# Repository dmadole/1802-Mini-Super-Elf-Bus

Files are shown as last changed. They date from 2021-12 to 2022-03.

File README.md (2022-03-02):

# 1802-Mini-Super-Elf-Bus-Adapter
This is a bus adapter card for the Quest Super Elf that adapts it to expansion cards for the [1802/Mini](https://github.com/dmadole/1802-Mini) system. It supports the following features:

* Connects to 50-pin expansion connector on Super Elf
* 64K of memory in two 32K RAM, EPROM, or EEPROM devices
* Supports 62C64, 62C256, 27C64, 27C256, 28C64, 28C256
* Can temporarily map a ROM at $8000 to $0000 with M key
* TTL level port with Q and selectable EF pin for soft serial
* Transmit and receive polarity selectable on serial port
* Buffered data bus for reliability across ribbon cable
* Additional pull-up resistors for improved rise time on inputs
* Voltage regulator allows powing expansion cards from Super Elf
* Mini-USB connector for independent 5 volt power input
* Form factor allows stacking or backplane by connector choice
* Highly annoted silkscreen documents most settings and pins

Gerber files for the PCBs and PDF schematics can be found in [Releases](https://github.com/dmadole/1802-Mini-Super-Elf-Bus/releases).

BOMS and any applicable errata or other notes can be found in [notes](https://github.com/dmadole/1802-Mini-Super-Elf-Bus/tree/main/notes).

For availability of kits and bare PCBs please see http://madole.net/1802/mini/kits

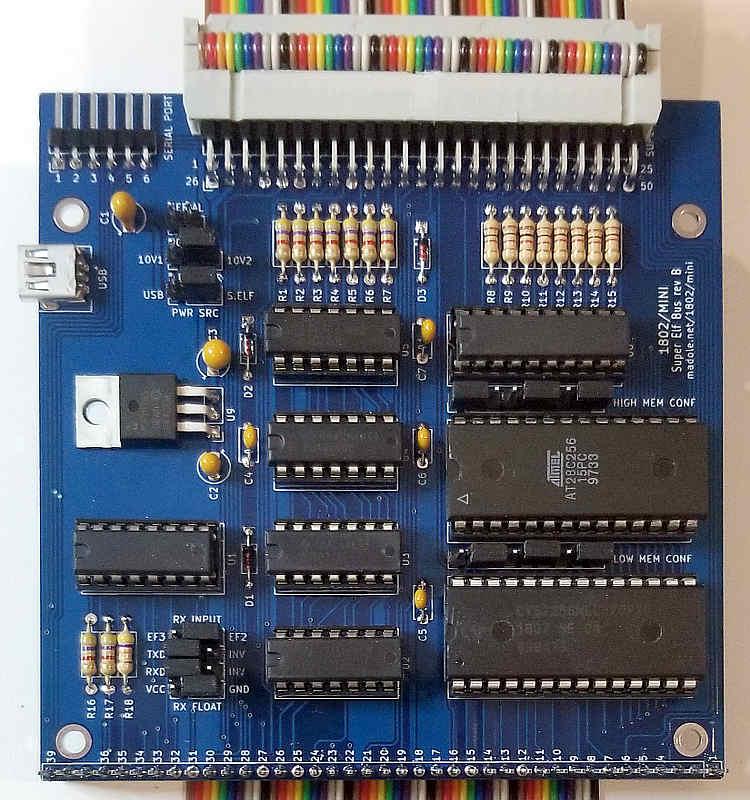
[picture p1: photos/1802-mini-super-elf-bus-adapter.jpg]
1802/Mini Super Elf Bus Adapter

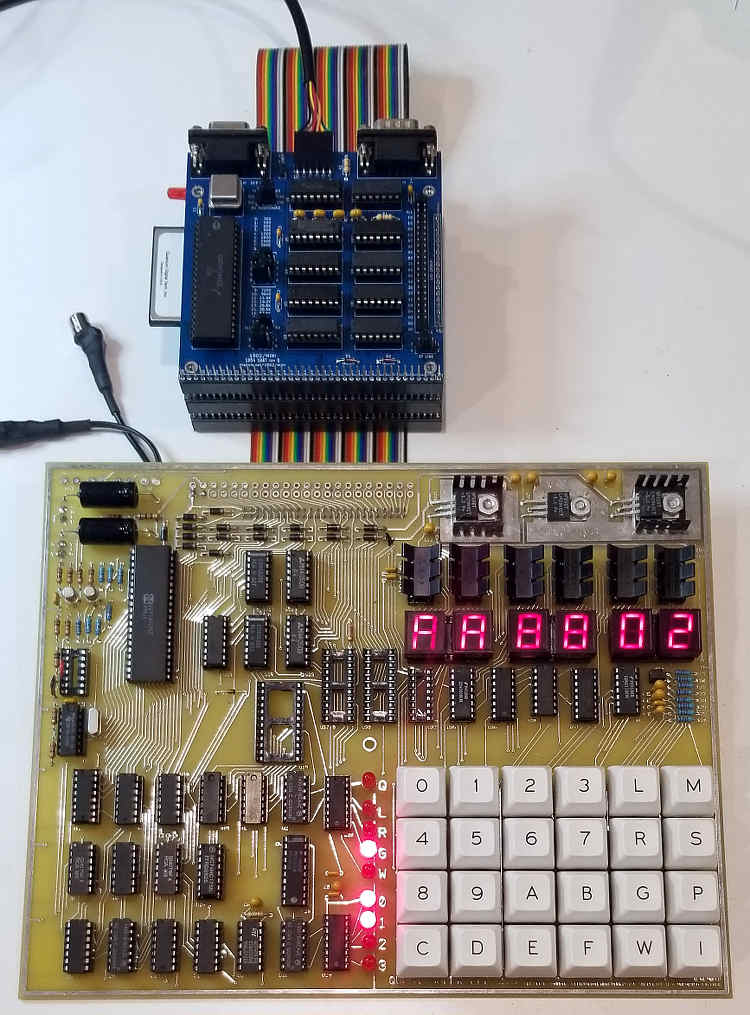
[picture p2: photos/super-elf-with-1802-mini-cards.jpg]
Super Elf with 1802/Mini Cards


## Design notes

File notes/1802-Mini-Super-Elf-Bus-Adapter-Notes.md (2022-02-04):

# 1802/Mini Super Elf Bus Adapter Notes

Please see any [applicable errata](https://github.com/dmadole/1802-Mini-Processor/tree/main/notes) before assembling.

## Super Elf Bus Connector

When soldering the 50-pin connector for the ribbon cable that goes to the Super Elf, if you are using an unshrouded connector, be sure to leave enough clearance from the board to be able to plug your connector in. By itself, a "standard" unshrouded connector sits too low to the board for a typical ribbon cable IDC connector to fit. The easy way to deal with this is to plug your cable into the connector before soldering the connector to the board.

The 50-pin connector should be installed on the "top" component side of the adapter board, and the 50-pin connector on the Super Elf should be installed on the "bottom" solder side of the Super Elf. If for some reason the 50-pin connector is already installed on the "top" component side of your Super Elf, you will need to install the connector on the adapter on the "bottom" solder side instead to compensate (or make a special ribbon cable with the even and odd pins reversed on one end).

## CLEAR Signal on Bus Connector

The bus adapter and most 1802/Mini peripheral cards need the 1802 CLEAR- signal, however this was not provided on the 50-pin expansion connector in the Super Elf design. Since the original on-board RAM is no longer needed with the bus adapter, the CS pin on the Super Elf expansion has been re-purposed to carry the CLEAR- signal, which requires slight modification to the Super Elf:

1. Remove the two 256-byte RAM chips
2. Solder a jumper from CLEAR- to CS

A convenient place to put the jumper is between U19 (1861) pin 8 (CLEAR-) and U27 (2101) pin 17 (CS) since these are adjacent chips and the jumper is short. The 22K pull-up resistor on the board for CS can be left in place.

Alternatively, if you don't want to modify the Super-Elf, you could lift the wire from the  CS pin in the ribbon cable and connect it somewhere on the board where CLEAR- is present, perhaps with a mini-hook clip. If you arrange to ground the CS pin on the ribbon connector where the wire would have been, it will not be necessary to remove the RAMs from the Super Elf. 

## Power Input Source

You can power the bus adapter from the Super Elf by using the on-board regulator by jumpering "PWR SRC" to "S.ELF" and selecting which of the two power busses from the Super Elf you want to use with the "S.ELF PWR" jumper. Otherwise, the bus adapter and expansion cards can be powered separately using the mini-USB connector by jumpering "PWR SRC" to "USB". Or it can be arranged to input power on the 1802/Mini bus VCC and GND pins.

## Memory Mapping

The low memory socket is mapped at 0000 and the high at 8000. Pressing the "M" key causes the high socket to appear at both 0000 and 8000 after system reset until the first read of an address at 8000 or above. This can be used to bootstrap a system from ROM that normally has RAM at 0000 by putting a jump instruction to high address space in the start of the ROM. Many existing ROM images work with this either intentionally or unintentionally as they start with a long jump instruction.

The "G" key will start execution with the RAM mapped at 0000 and so can be used to execute code in RAM that was input from the keypad.

## Serial Port Polarity

The normal RX and TX jumper settings for use with typical 5 volt level serial interfaces and most software is TX and RX non-inverted, and RX at VCC. These can need to be reversed, however, depending on how software is written. Use EF3 for RX for running membership card software or EF2 for running Pico/Elf software.

## Serial Port Speed

The timing parameters of the standard software UART in the Elf/OS BIOS are not well suited to the Super Elf clock rate, so the highest serial speed that can be expected at 1.79 MHZ is 1200 baud, or at 3.58 MHz is 2400 baud. The nitro software UART can be loaded though to use up to 9600 baud at 1.79 Mhz or 19200 baud at 3.58 Mhz. Be sure to use the "-k" option to nitro to specify the clock rate if also specifying a baud rate, for example, "nitro -k 1790 9600"

## Jumper Settings

The following are the recommended jumper settings for use with Elf/OS. These assume 32K RAM in low memory from 0000-7FFF and 32K EEPROM in high memory from 8000-FFFF, use of EF2 for serial input, and startup from ROM. These give compatibility with software intended for the Pico/Elf and so is most convenient for use with software for Elf/OS.

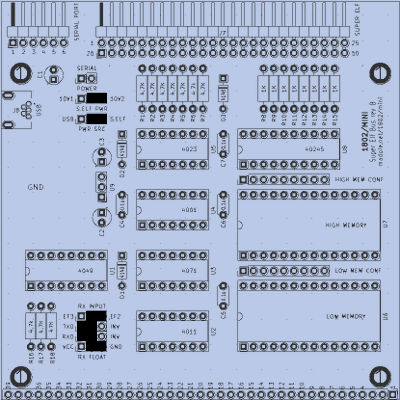
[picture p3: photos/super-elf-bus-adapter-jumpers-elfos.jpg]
Super Elf Bus Adapter Jumpers


If you are using an 1802/Mini specific build of Elf/OS BIOS that supports the 1854 UART with auto-detection of which port to use, you will want to set the RX GND jumper instead of RX VCC. This allows the BIOS to detect on EF2 when no cable is connected. Note that this does prevent EF2 from being used for anything else. This firmware is here:

https://github.com/dmadole/1802-Mini/tree/master/firmware

There is a specific build for the Super Elf, which has the clock rate defined as 1790 KHz and the baud rate fixed at 1200 baud.

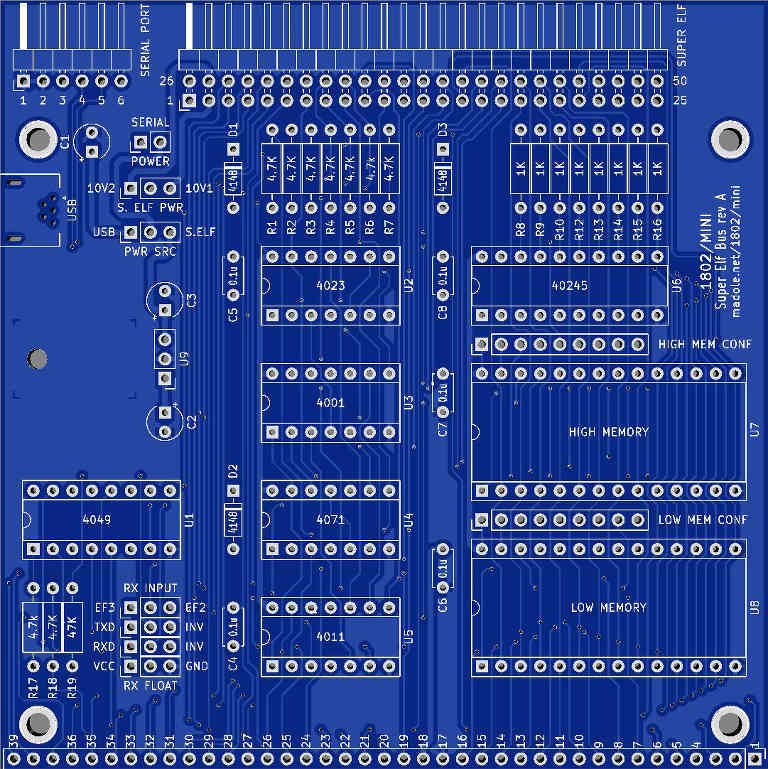
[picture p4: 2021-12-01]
photos/1802-Mini-Super-Elf-Bus-Rev-A-Rendering.jpg

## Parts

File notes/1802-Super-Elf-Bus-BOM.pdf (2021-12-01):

SUPER ELF BUS ADAPTER

Qty | Description | Manufacturer Manufacturer # | Vendor | Vendor # | Price | Qty | Total

Integrated Circuits
1 | 32K x 8 CMOS SRAM | Sharp | LM62256L-70 | Jameco | 82472 | 3.95 | 1.00 | 3.95
1 | 32K x 8 CMOS EEPROM | Atmel | 28C256-25 | Jameco | 74878 | 4.95 | 1.00 | 4.95
1 | CD4001 | TI | CD4001BE | Digikey | 296-2028-ND | 0.68 | 1.00 | 0.68
1 | CD4011 | TI | CD4011BE | Digikey | 296-2031-ND | 0.68 | 1.00 | 0.68
1 | CD4023 | TI | CD4023BE | Digikey | 296-2041-ND | 0.68 | 1.00 | 0.68
1 | CD4071 | TI | CD4071BE | Digikey | 296-2062-ND | 0.68 | 1.00 | 0.68
1 | CD4049 | TI | CD4049UBE | Digikey | 296-2055-5-ND | 0.68 | 1.00 | 0.68
1 | CD40245 (or 74C245 or 74HC245) | TI | SN74HC245N | Digikey | 296-1584-5-ND | 0.68 | 1.00 | 0.68
1 | LM2940CT | TI | LM2940CT-5.0/NOPB | Digikey | LM2940CT-5.0/NOPB-ND | 1.96 | 1.00 | 1.96

Discrete Components
8 | Resistor 1/4 watt 1K | Stackpole | CF14JT1K00 | Digikey | CF14JT1K00CT | 0.10 | 8.00 | 0.80
9 | Resistor 1/4 watt 4.7K | Stackpole | CF14JT4K70 | Digikey | CF14JT4K70CT-ND | 0.10 | 9.00 | 0.90
1 | Resistor 1/4 watt 47K | Stackpole | CF14JT47K0 | Digikey | CF14JT47K0CT-ND | 0.10 | 1.00 | 0.10
3 | Diode 1N4148 | ON Semi | 1N4148 | Digikey | 1N4148FS-ND | 0.10 | 3.00 | 0.30
5 | Ceramic capacitor 0.1uF radial 0.2" | AVX | SR215C104KAA | Digikey | 478-2472-ND | 0.51 | 5.00 | 2.55
1 | Tantalum capacitor 0.47uF radial 0.1" | AVX | TAP474K035SCS | Digikey | 478-1900-ND | 0.68 | 1.00 | 0.68
1 | Tantalum capacitor 10uF radial 0.1" | AVX | TAP106K010SCS | Digikey | 478-1838-ND | 0.80 | 1.00 | 0.80
1 | Tantalum capacitor 22uF radial 0.1" | AVX | TAP226K010SCS | Digikey | 478-1874-ND | 1.13 | 1.00 | 1.13

Interconnects
1 | Straight header 2 pins 0.1" | Sullins | PREC002SAAN-RC | Digikey | S1012EC-02-ND | 0.06 | 1.00 | 0.06
6 | Straight header 3 pins 0.1" | Sullins | PREC003SAAN-RC | Digikey | S1012EC-03-ND | 0.09 | 6.00 | 0.54
2 | Straight header 9 pins 0.1" | Sullins | PREC009SAAN-RC | Digikey | S1012EC-09-ND | 0.21 | 2.00 | 0.42
1 | Right-angle header 6 pins 0.1" | Sullins | PREC006SBAN-M71RC | Digikey | S1112EC-06-ND | 0.19 | 1.00 | 0.19
1 | Right-angle header 50 pins 0.1" | Sullins | PREC025DBAN-M71RC | Digikey | S2112EC-25-ND | 1.41 | 1.00 | 1.41
13 | Jumper shunts 0.1" | Sullins | STC02SYAN | Digikey | S9000-ND | 0.10 13.00 | 1.30
1 | Socket 39 pin 0.1" long tail for stacking | Samtec | SSQ-139-03-T-S | Digikey | SAM1206-39-ND | 4.52 | 1.00 | 4.52
1 | Mini-USB receptable AB | Molex | 565790519 | Digikey | WM17121-ND | 2.54 | 1.00 | 2.54

Sockets
2 | DIP socket 28 pin 0.6" | On Shore | ED28DT | Digikey | ED3052-5-ND | 0.34 | 2.00 | 0.68
1 | DIP socket 20 pin 0.3" | On Shore | ED20DT | Digikey | ED3054-5-ND | 0.26 | 1.00 | 0.26
1 | DIP socket 16 pin 0.3" | On Shore | ED16DT | Digikey | ED3046-5-ND | 0.19 | 1.00 | 0.19
4 | DIP socket 14 pin 0.3" | On Shore | ED14DT | Digikey | ED3045-5-ND | 0.19 | 4.00 | 0.76

Mechanical
4 | 0.5 inch standoff spacer | RAF | 4505-440-AL-7 | Jameco | 393474 | 0.49 | 4.00 | 1.96
1 | Circuit Board | Madole | | JLCPCB | | 3.00 | 1.00 | 3.00
| | | | | | Total | | 40.03

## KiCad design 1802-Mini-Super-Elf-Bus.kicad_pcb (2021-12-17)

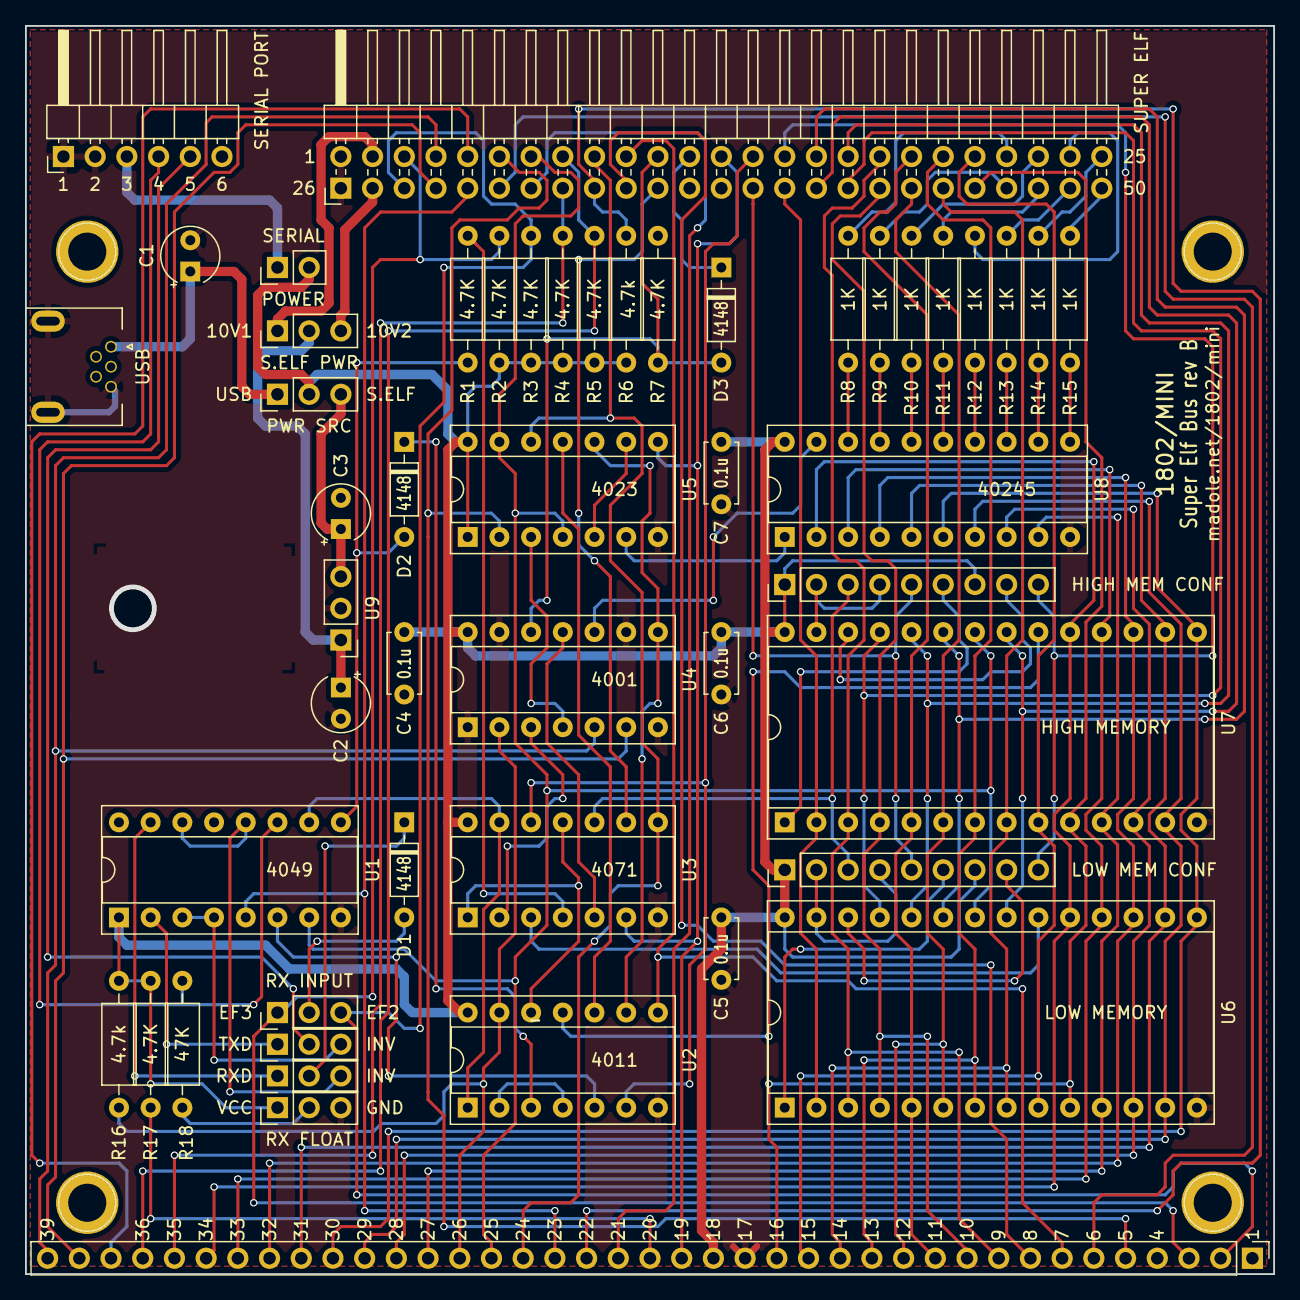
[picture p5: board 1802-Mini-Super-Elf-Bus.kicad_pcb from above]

Board: 2 copper layers, 100.0 x 100.0 mm, 54 parts (0 on the bottom side), 103 nets.

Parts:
C1: 10uF; CP_Radial_Tantal_D4.5mm_P2.50mm
C2: 0.47uF; CP_Radial_Tantal_D4.5mm_P2.50mm
C3: 22uF; CP_Radial_Tantal_D4.5mm_P2.50mm
C4, C5, C6, C7: 0.1u; C_Disc_D4.7mm_W2.5mm_P5.00mm
D1, D2, D3: 4148; D_DO-35_SOD27_P7.62mm_Horizontal
J1, J2, J3, J4: Mount; 1pin
J5: 1802/Mini Bus; PinHeader_1x39_P2.54mm_Vertical
J6: SLOT_1_CONFIG; PinHeader_1x09_P2.54mm_Vertical
J7: Super Elf Bus; PinHeader_2x25_P2.54mm_Horizontal_Row1_Row2
J8: USB PWR; USB_Mini-AB_Molex_56579_0519
J9: Serial Port; PinHeader_1x06_P2.54mm_Horizontal
J10: SLOT_2_CONFIG; PinHeader_1x09_P2.54mm_Vertical
JP1: POWER; PinHeader_1x02_P2.54mm_Vertical
JP2, JP3: PWR SRC; PinHeader_1x03_P2.54mm_Vertical
JP8: TX_INV; PinHeader_1x03_P2.54mm_Vertical
JP9: RX_SEL; PinHeader_1x03_P2.54mm_Vertical
JP10: RX_INV; PinHeader_1x03_P2.54mm_Vertical
JP11: RX_IDL; PinHeader_1x03_P2.54mm_Vertical
R1, R2, R3, R4, R5, R6, R17: 4.7K; R_Axial_DIN0207_L6.3mm_D2.5mm_P10.16mm_Horizontal
R7, R16: 4.7k; R_Axial_DIN0207_L6.3mm_D2.5mm_P10.16mm_Horizontal
R8, R9, R10, R11, R12, R13, R14, R15: 1K; R_Axial_DIN0207_L6.3mm_D2.5mm_P10.16mm_Horizontal
R18: 47K; R_Axial_DIN0207_L6.3mm_D2.5mm_P10.16mm_Horizontal
U1: 4049; DIP-16_W7.62mm_Socket
U2: 4011; DIP-14_W7.62mm_Socket
U3: 4071; DIP-14_W7.62mm_Socket
U4: 4001; DIP-14_W7.62mm_Socket
U5: 4023; DIP-14_W7.62mm_Socket
U6: LO_MEM; DIP-28_W15.24mm_Socket
U7: HI_MEM; DIP-28_W15.24mm_Socket
U8: 40245; DIP-20_W7.62mm_Socket
U9: LM2940CT; PinHeader_1x03_P2.54mm_Vertical

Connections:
10V1: J7.27, JP2.1
10V2: J7.2, JP2.3
/A0: J5.16, J7.21, U6.10, U7.10
/A1: J5.15, J7.46, U6.9, U7.9
/A2: J5.14, J7.20, U6.8, U7.8
/A3: J5.13, J7.45, U6.7, U7.7
/A4: J5.12, J7.19, U6.6, U7.6
/A5: J5.11, J7.44, U6.5, U7.5
/A6: J5.10, J7.18, U6.4, U7.4
/A7: J5.9, J7.43, U6.3, U7.3
/A8: J7.17, U6.25, U7.25
/A9: J7.42, U6.24, U7.24
/A10: J7.16, U6.21, U7.21
/A11: J7.41, U6.23, U7.23
/A12: J7.15, U6.2, U7.2
/A13: J6.9, J7.40, J10.9
/A14: J6.5, J7.14, J10.5
/BUS0: J5.27, U6.11, U7.11, U8.9
/BUS1: J5.28, U6.12, U7.12, U8.8
/BUS2: J5.29, U6.13, U7.13, U8.7
/BUS3: J5.30, U6.15, U7.15, U8.6
/BUS4: J5.31, U6.16, U7.16, U8.5
/BUS5: J5.32, U6.17, U7.17, U8.4
/BUS6: J5.33, U6.18, U7.18, U8.3
/BUS7: J5.34, U6.19, U7.19, U8.2
/D0: J7.25, R15.2
/D1: J7.50, R14.2
/D2: J7.24, R13.2
/D3: J7.49, R12.2
/D4: J7.23, R11.2
/D5: J7.48, R10.2
/D6: J7.22, R9.2
/D7: J7.47, R8.2
A15: J7.39, U2.6, U3.12
CLOCK: J5.21, J7.7
DIR: U5.6, U8.1
G: D3.1, J7.37
GND: C1.2, C2.2, C3.2, C4.2, C5.2, C6.2, C7.2, J5.17, J7.1, J7.26, J8.5, J8.6, J9.1, J9.2, JP11.3, R7.1, U1.8, U2.7, U3.7, U4.1, U4.7, U4.9, U4.13, U5.7, U6.14, U7.14, U8.10, U9.2
M: D3.2, J7.36, R7.2, U4.12
MEN: J5.26, R16.1, U2.13, U4.2
MP: J7.11, U3.9
N0: J5.39, J7.29, U4.5
N1: J5.38, J7.4, U4.6
N2: J5.37, J7.30
unnamed: C1.1, J8.1, JP3.1
unnamed: C2.1, JP2.2, U9.1
unnamed: C3.1, JP3.3, U9.3
unnamed: D1.1, JP10.2
unnamed: D1.2, JP9.2
unnamed: D2.1, U2.3
unnamed: D2.2, R1.2, U1.9
unnamed: J6.2, J6.4, U6.27
unnamed: J6.6, U6.1
unnamed: J6.8, U6.26
unnamed: J9.3, JP1.1
unnamed: J9.4, R18.2, U1.11
unnamed: J9.5, JP8.2
unnamed: J10.2, J10.4, U7.27
unnamed: J10.6, U7.1
unnamed: J10.8, U7.26
unnamed: JP8.1, U1.2
unnamed: JP8.3, U1.3, U1.4
unnamed: JP10.1, U1.15
unnamed: JP10.3, U1.12, U1.14
unnamed: JP11.2, R18.1
unnamed: R1.1, U3.4
unnamed: R8.1, U8.18
unnamed: R9.1, U8.17
unnamed: R10.1, U8.16
unnamed: R11.1, U8.15
unnamed: R12.1, U8.14
unnamed: R13.1, U8.13
unnamed: R14.1, U8.12
unnamed: R15.1, U8.11
unnamed: U1.6, U2.5
unnamed: U1.10, U2.1, U3.13
unnamed: U2.2, U2.4
unnamed: U2.9, U4.8, U5.10
unnamed: U2.10, U5.11
unnamed: U2.12, U3.1, U3.11
unnamed: U3.2, U4.3
unnamed: U3.5, U4.11
unnamed: U4.4, U5.3
unnamed: U5.5, U5.9
Q: J5.23, J7.5, U1.5
SC0: J5.6, J7.6
SC1: J5.5, J7.31, U5.2
TPA: J5.8, J7.10
TPB: J5.7, J7.35, U2.8
VCC: C4.1, C5.1, C6.1, C7.1, J5.18, J6.1, J6.7, J10.1, J10.7, JP1.2, JP3.2, JP11.1, R2.1, R3.1, R4.1, R5.1, R6.1, R16.2, R17.1, U1.1, U2.14, U3.14, U4.14, U5.1, U5.14, U6.28, U7.28, U8.20
~CLEAR: J5.19, J7.38, U3.6, U5.8
~CS_HI: U2.11, U7.20
~CS_LO: U3.3, U6.20
~DMAIN: J5.36, J7.33, R5.2
~DMAOUT: J5.35, J7.8, R4.2
~EF2: J5.2, J7.3, JP9.3, R3.2
~EF3: J5.3, J7.28, JP9.1, R2.2
~INT: J5.22, J7.9, R6.2
~MRD: J5.25, J7.32, U1.7, U5.4, U5.13, U6.22, U7.22
~MWR: J5.24, J7.34, U3.8, U5.12
~OE: U4.10, U8.19
~WAIT: J5.20, R17.2
~WE: J6.3, J10.3, U3.10

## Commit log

2021-12-17 Rev B updates
    [1802-Mini-Super-Elf-Bus-B_Cu.gbl, 1802-Mini-Super-Elf-Bus-B_Mask.gbs, 1802-Mini-Super-Elf-Bus-B_Paste.gbp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]
2022-02-04 Remove irrelevant reference to Q LED
